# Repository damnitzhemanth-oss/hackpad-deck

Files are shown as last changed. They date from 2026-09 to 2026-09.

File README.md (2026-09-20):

# MacroPad
A 9-key *multi-functional* macropad with rotary encoder, OLED, and addressable RGB LEDs

*Note : This ReadMe is written by a human known as Hemanth from India, I am new to this and learning every day. Please highlight the mistakes I may have made.*

## Overview

This is my first **Stardance HackClub** project. I have officially worked on this project for 22+ hours. I want to thank all the people to who are responsible in creation of these organizations. 

## Functions 

- Modes like Dev, Editor, etc with different presets of keys.
- Contains a satisfying Mini Game.
(*Discussed in **depth** in upcoming sections*)

Assembly Render

## PCB  Design

I was already well versed with simple hardware projects using **Arduino UNO** and **ESP 8266**, but even though I knew about PCBs I never used them as they are expensive. Learning *KiCad* was pretty straight forward and easy.

Mainly routing was a bit challenging but everything else was easy. DRC have 0 errors except silkscreen warnings. 

## PCB Gallery

1. SCHEMATIC SVG 

Schematic Picture

2. Screenshots

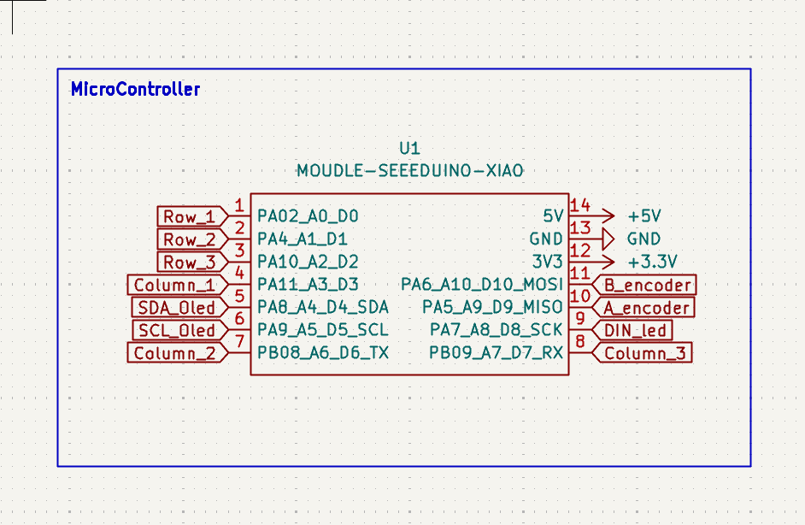
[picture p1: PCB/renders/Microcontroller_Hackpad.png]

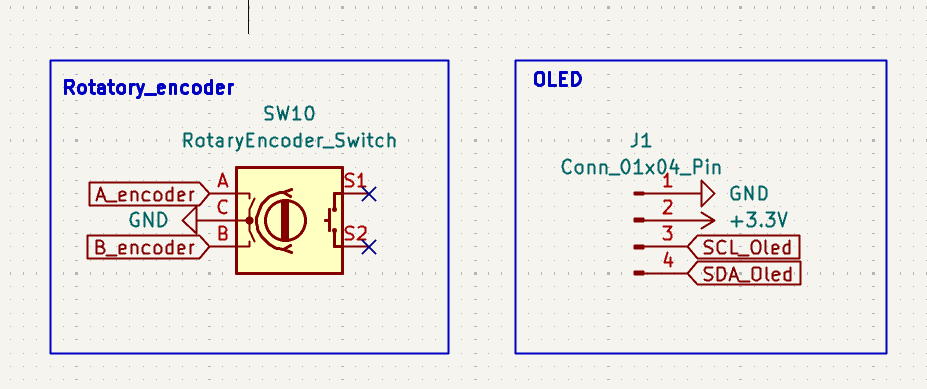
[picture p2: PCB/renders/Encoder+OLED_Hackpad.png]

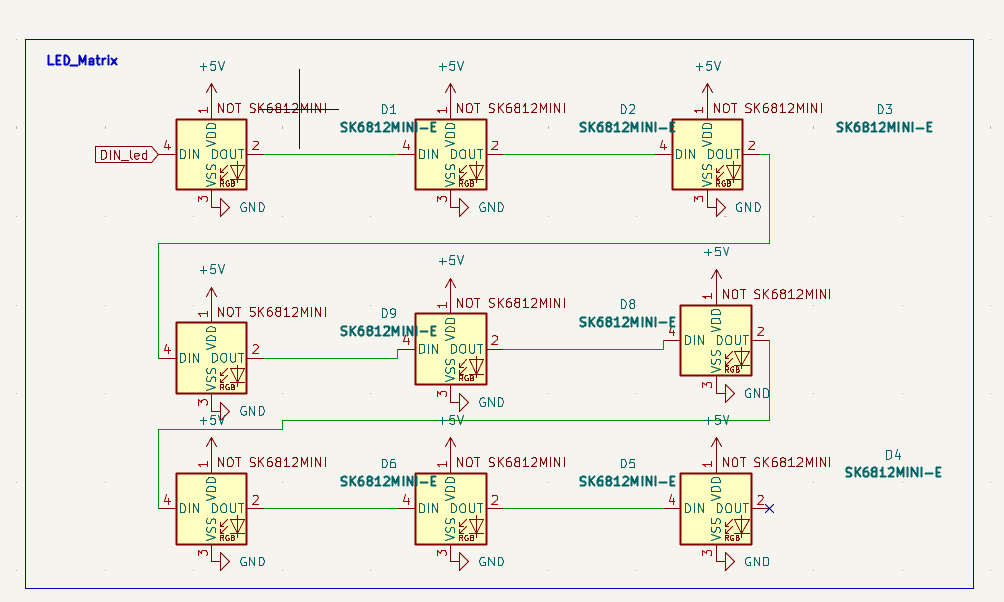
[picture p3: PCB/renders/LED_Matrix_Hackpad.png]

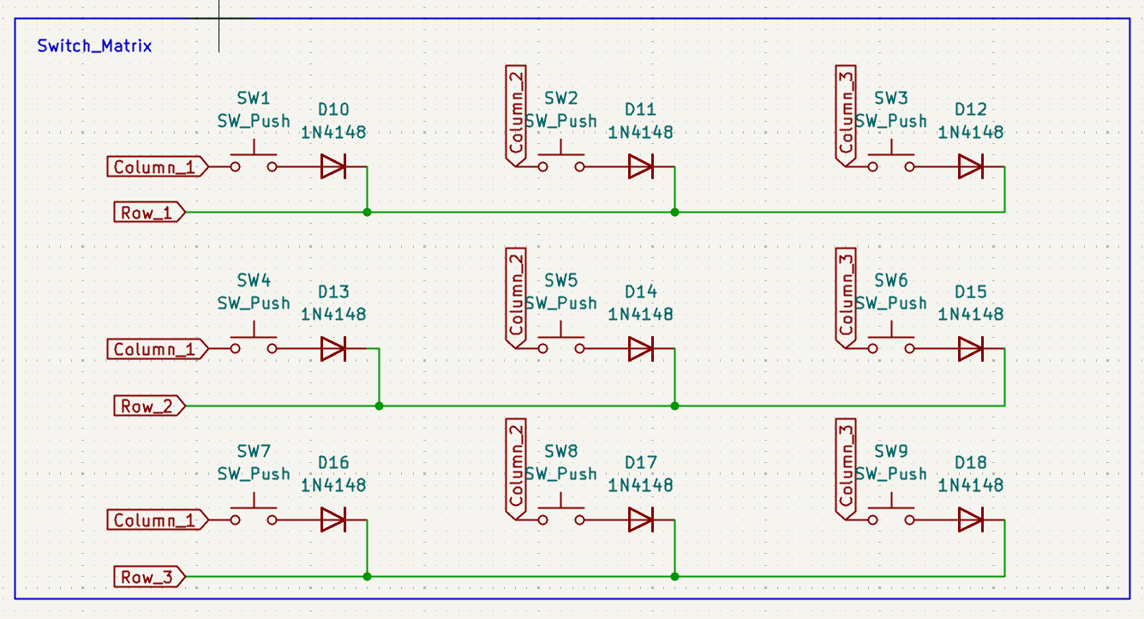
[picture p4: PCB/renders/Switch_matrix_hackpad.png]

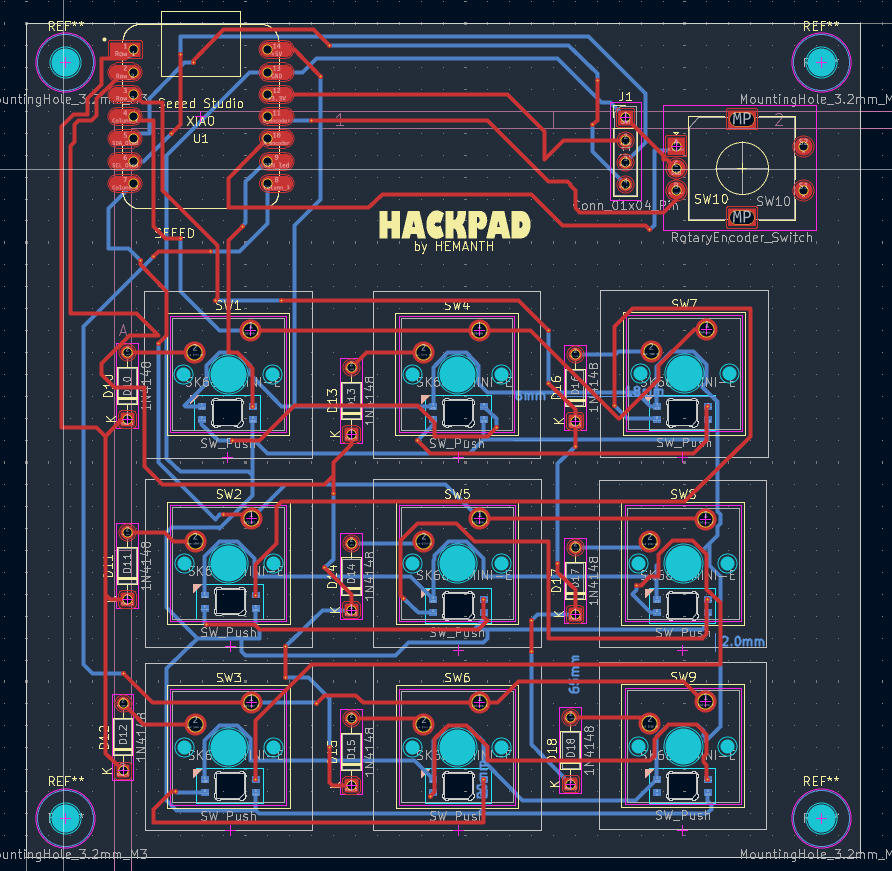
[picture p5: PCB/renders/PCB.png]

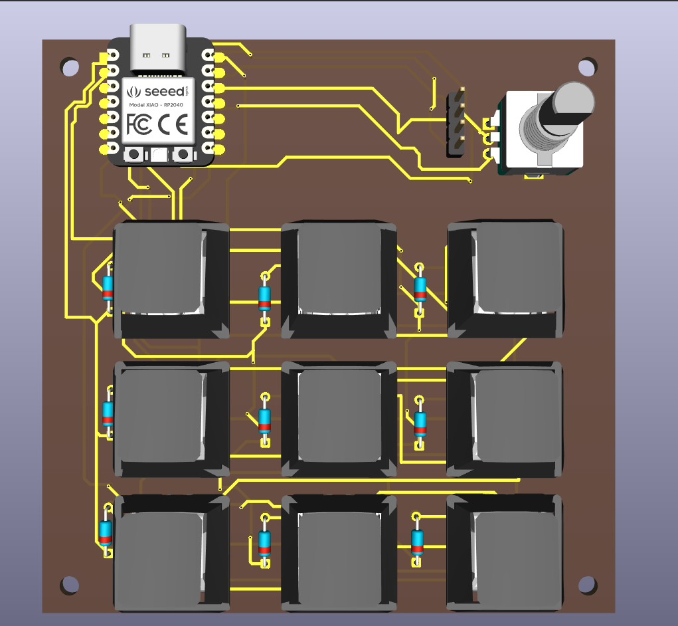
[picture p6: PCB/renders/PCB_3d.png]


## CAD Design

Cad was one of the field I had zero ball knowledge about. So designing it was fun but also was a pain. Due to daily internet cap I was not able to download Fusion 360, so OnShape was the way to go.
The design mainly consists of Base plate with Heatset Inserts and Top Plate with holes for M3 screws. PCB gets sandwiched between. All this was done in keeping +0.2 mm tolerance in mind.

## Cad Gallery.

Assembly Render
Assembly Render
Assembly Render
Plates
Plates
Plates
Plates

##  Functions

| Feature | Description |
|---|---|
|  **6 Modes** | Dev, Media, Video, Macro, Aesthetic, Games |
|  **Whack-a-LED Game** | Press the lit switch before time runs out |
| **DJ Mode** | Rainbow RGB animation across all 9 LEDs |
|  **Snowfall OLED** | Idle screen shows falling snowflakes |
|  **Rotary Encoder** | Volume control on every mode |
| **Per-Key RGB** | 9 addressable SK6812MINI-E LEDs |
|  **Live OLED Feedback** | Shows mode, key presses, and game score |

---

##  Modes

Cycle modes by **long-pressing SW7** (bottom-left key).

### 1. DEV — Editor & Typing
| Key | Action |
|-----|---|
| SW1–SW9 | Number keys 2–9 (numpad layout) |
| SW7 (tap) | ESC |
| SW7 (hold) | Next mode |

### 2. MEDIA — Playback Controls
| Key | Action |
|-----|---|
| SW1 | Play / Pause |
| SW2 | Stop |
| SW3 | Mute |
| SW4 | Previous Track |
| SW6 | Next Track |
| SW8 | Volume Down |
| SW9 | Volume Up |

### 3. VIDEO — DaVinci Resolve Editing
| Key | Action |
|-----|---|
| SW1 | Split Clip |
| SW2 | Undo |
| SW3 | Redo |
| SW4 | Mark In |
| SW5 | Mark Out |
| SW6 | Paste Attributes |
| SW8 | Play / Pause |
| SW9 | Backspace |

### 4. MACRO — Launcher & Productivity
| Key | Action |
|-----|---|
| SW1–SW3 | Open App 1 / 2 / 3 |
| SW4–SW6 | Copy / Paste / Cut |
| SW8–SW9 | Select All / Save |

### 5. AESTHETIC — DJ Mode 
RGB LEDs dance through a rotating rainbow. No key output — pure visual vibes.

### 6. GAMES — Whack-a-LED 
A random LED lights up **green**. Press its switch within **3 seconds** to score. Wrong key or timeout resets your score to 0 and flashes all LEDs red.

---

## Bill of Materials

| # | Component | Qty | Source |
|---|---|-----|---|
| 1 | Seeed XIAO RP2040 | 1 | Hack Club Kit |
| 2 | Gateron KS-3 MX Switches | 9 | Hack Club Kit |
| 3 | 1N4148 Through-hole Diodes | 9 | Hack Club Kit |
| 4 | Alps EC11E Rotary Encoder | 1 | Hack Club Kit |
| 5 | SK6812MINI-E RGB LEDs | 9 | Hack Club Kit |
| 6 | 0.91" SSD1306 OLED Display (128×32) | 1 | Hack Club Kit |
| 7 | White DSA Keycaps | 9 | Hack Club Kit |
| 8 | M3×16mm Screws *(trim to 13mm)* | 4 | Hack Club Kit |
| 9 | M3×5mm×4mm Heatset Inserts | 4 | Hack Club Kit |
| 10 | 3D Printed Case (Base + Top Plate) | 1 set | 

---

## Firmware

Written in **Python** using **KMK** on **CircuitPython**.

See [`Firmware/main.py`](Firmware/main.py) for the full source.

---

## AI USAGE

I used AI/ Online resources to learn but never automate anything. You can checkout Lapse recording from lookout too.

## Credits

- **[Hack Club](https://hackclub.com/)** — for the kit and the program
- **Star Dance** — for organizing this buildathon
- **[KMK Firmware](https://github.com/KMKfw/kmk_firmware)** — Python keyboard firmware
- **Hack Club Hackpad team** — for the guides and KiCad care package
- Special shoutout to Logan Peterson, whose design inspired me a lot.

---

##  License

Open source, but you are responsible if it creates a black hole in your house.

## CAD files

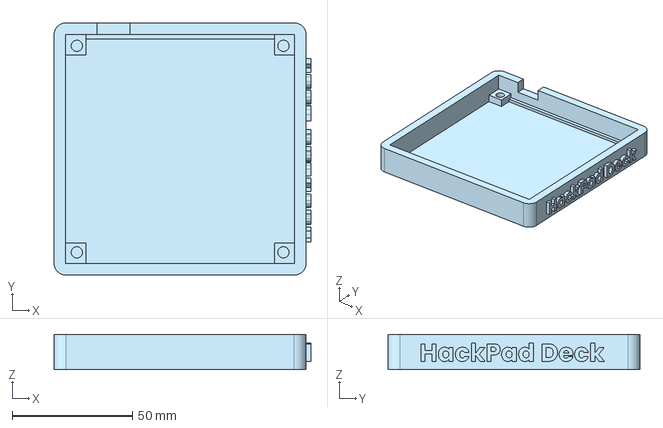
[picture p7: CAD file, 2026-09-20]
production/Base_Plate.step
107.0 x 105.0 x 14.6 mm

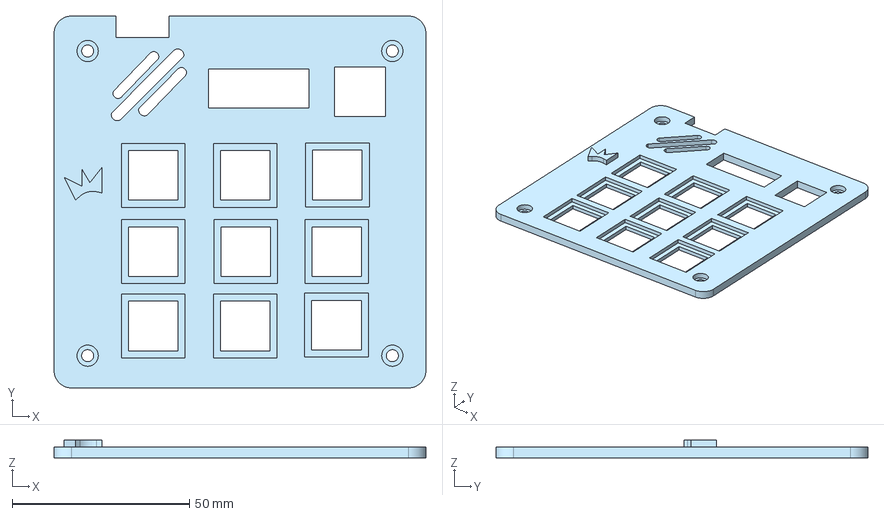
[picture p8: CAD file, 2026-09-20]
production/Top_plate.step
105.0 x 105.0 x 5.00 mm

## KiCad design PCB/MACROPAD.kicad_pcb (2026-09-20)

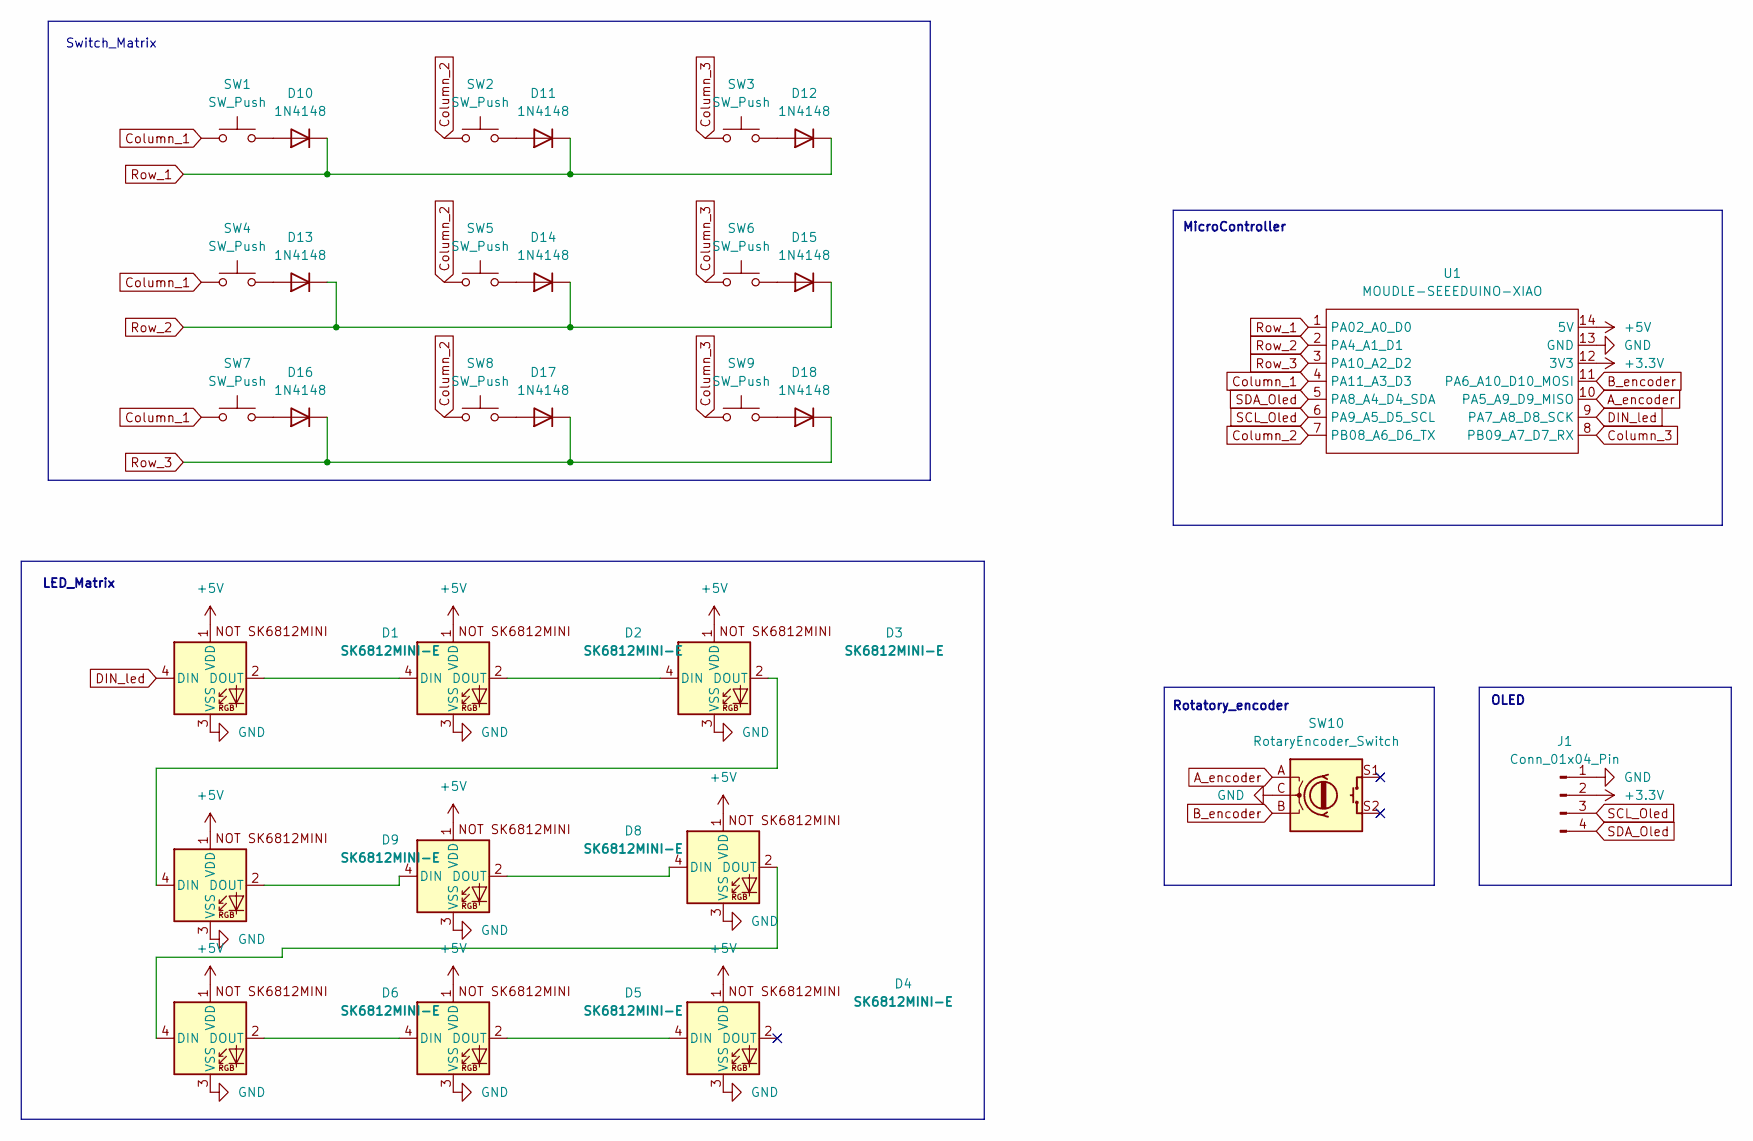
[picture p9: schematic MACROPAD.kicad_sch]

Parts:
D1, D2, D3, D4, D5, D6, D7, D8, D9: SK6812MINI-E; MX_SK6812MINI-E_fixed_mount_with3D
D10, D11, D12, D13, D14, D15, D16, D17, D18: 1N4148; D_DO-35_SOD27_P7.62mm_Horizontal
J1: Conn_01x04_Pin; Adafruit_SSD1306
SW1, SW2, SW3, SW4, SW5, SW6, SW7, SW8, SW9: SW_Push; SW_Cherry_MX_1.00u_PCB_3d
SW10: RotaryEncoder_Switch; RotaryEncoder_Alps_EC11E-Switch_Vertical_H20mm
U1: MOUDLE-SEEEDUINO-XIAO; XIAO-Generic-Hybrid-14P-2.54-21X17.8MM

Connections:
+3.3V: J1.2, U1.12 (3V3)
+5V: D1.1 (VDD), D2.1 (VDD), D3.1 (VDD), D4.1 (VDD), D5.1 (VDD), D6.1 (VDD), D7.1 (VDD), D8.1 (VDD), D9.1 (VDD), U1.14 (5V)
A_encoder: SW10.A, U1.10 (PA5_A9_D9_MISO)
B_encoder: SW10.B, U1.11 (PA6_A10_D10_MOSI)
Column_1: SW1.1, SW4.1, SW7.1, U1.4 (PA11_A3_D3)
Column_2: SW2.1, SW5.1, SW8.1, U1.7 (PB08_A6_D6_TX)
Column_3: SW3.1, SW6.1, SW9.1, U1.8 (PB09_A7_D7_RX)
DIN_led: D1.4 (DIN), U1.9 (PA7_A8_D8_SCK)
GND: D1.3 (VSS), D2.3 (VSS), D3.3 (VSS), D4.3 (VSS), D5.3 (VSS), D6.3 (VSS), D7.3 (VSS), D8.3 (VSS), D9.3 (VSS), J1.1, SW10.C, U1.13 (GND)
unnamed: D1.2 (DOUT), D2.4 (DIN)
unnamed: D2.2 (DOUT), D3.4 (DIN)
unnamed: D3.2 (DOUT), D9.4 (DIN)
unnamed: D4.4 (DIN), D5.2 (DOUT)
unnamed: D5.4 (DIN), D6.2 (DOUT)
unnamed: D6.4 (DIN), D7.2 (DOUT)
unnamed: D7.4 (DIN), D8.2 (DOUT)
unnamed: D8.4 (DIN), D9.2 (DOUT)
unnamed: D10.2 (A), SW1.2
unnamed: D11.2 (A), SW2.2
unnamed: D12.2 (A), SW3.2
unnamed: D13.2 (A), SW4.2
unnamed: D14.2 (A), SW5.2
unnamed: D15.2 (A), SW6.2
unnamed: D16.2 (A), SW7.2
unnamed: D17.2 (A), SW8.2
unnamed: D18.2 (A), SW9.2
Row_1: D10.1 (K), D11.1 (K), D12.1 (K), U1.1 (PA02_A0_D0)
Row_2: D13.1 (K), D14.1 (K), D15.1 (K), U1.2 (PA4_A1_D1)
Row_3: D16.1 (K), D17.1 (K), D18.1 (K), U1.3 (PA10_A2_D2)
SCL_Oled: J1.3, U1.6 (PA9_A5_D5_SCL)
SDA_Oled: J1.4, U1.5 (PA8_A4_D4_SDA)

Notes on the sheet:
LED_Matrix
MicroController
Rotatory_encoder
Switch_Matrix
OLED

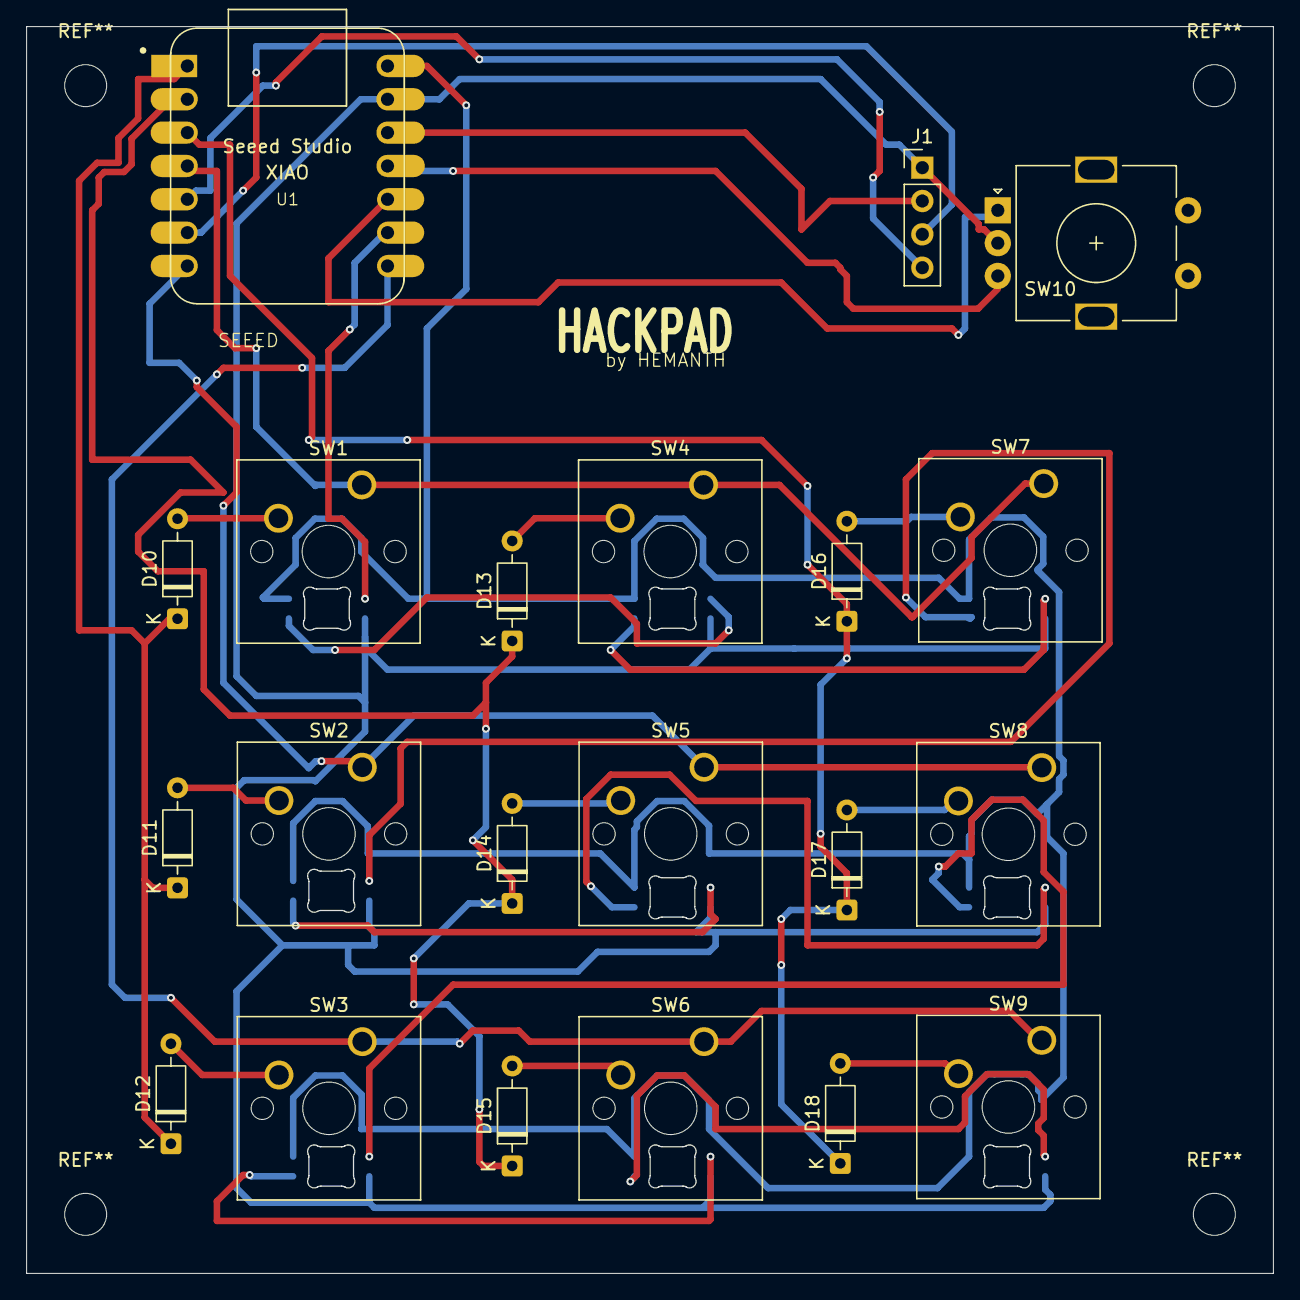
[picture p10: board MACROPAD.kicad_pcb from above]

Board: 2 copper layers, 95.0 x 95.0 mm, 30 parts (0 on the bottom side), 31 nets.

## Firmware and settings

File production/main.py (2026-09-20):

import board
import time
import random
import busio
import displayio
import terminalio
from adafruit_display_text import label
import adafruit_displayio_ssd1306

from kmk.kmk_keyboard import KMKKeyboard
from kmk.keys import KC, Key
from kmk.scanners import DiodeOrientation
from kmk.modules.layers import Layers
from kmk.modules.encoder import EncoderHandler
from kmk.modules.holdtap import HoldTap
from kmk.extensions.RGB import RGB, AnimationModes
from kmk.modules import Module

keyboard = KMKKeyboard()

keyboard.row_pins = (board.D0, board.D1, board.D2)
keyboard.col_pins = (board.D3, board.D6, board.D7)
keyboard.diode_orientation = DiodeOrientation.COL2ROW

MODE_NAMES = ["DEV", "MEDIA", "VIDEO", "MACRO", "AESTHETIC", "GAMES"]
current_mode = 0

MODE_COLORS = {
    0: {"idle": (0, 0, 40),    "accent": (255, 255, 255)},
    1: {"idle": (40, 0, 40),   "accent": (0, 255, 60)},
    2: {"idle": (50, 20, 0),   "accent": (0, 200, 255)},
    3: {"idle": (40, 0, 0),    "accent": (255, 220, 0)},
    4: {"idle": (0, 0, 0),     "accent": (0, 0, 0)},
    5: {"idle": (0, 0, 0),     "accent": (0, 0, 0)},
}

keyboard.active_layers = [current_mode]

layers_ext = Layers()
keyboard.modules.append(layers_ext)


class ModeCycleKey(Key):
    def on_press(self, keyboard):
        global current_mode
        current_mode = (current_mode + 1) % len(MODE_NAMES)
        keyboard.active_layers = [current_mode]
        status.on_mode_changed()


MODE_CYCLE = ModeCycleKey()

hold_tap = HoldTap(tap_time=200)
keyboard.modules.append(hold_tap)

SW7_HOLDTAP = KC.HT(KC.ESC, MODE_CYCLE)

keyboard.keymap = [
    [
        KC.N7, KC.N8, KC.N9,
        KC.N4, KC.N5, KC.N6,
        SW7_HOLDTAP, KC.N2, KC.N3,
    ],
    [
        KC.MPLY, KC.MSTP, KC.MUTE,
        KC.MPRV, KC.NO,   KC.MNXT,
        SW7_HOLDTAP, KC.VOLD, KC.VOLU,
    ],
    [
        KC.LCTL(KC.LSFT(KC.N3)),
        KC.LCTL(KC.Z),
        KC.LCTL(KC.LSFT(KC.Z)),
        KC.I,
        KC.O,
        KC.LCTL(KC.LSFT(KC.V)),
        SW7_HOLDTAP, KC.SPC, KC.BSPC,
    ],
    [
        KC.LGUI(KC.N1), KC.LGUI(KC.N2), KC.LGUI(KC.N3),
        KC.LCTL(KC.C),  KC.LCTL(KC.V),  KC.LCTL(KC.X),
        SW7_HOLDTAP,    KC.LCTL(KC.A),  KC.LCTL(KC.S),
    ],
    [
        KC.NO, KC.NO, KC.NO,
        KC.NO, KC.NO, KC.NO,
        SW7_HOLDTAP, KC.NO, KC.NO,
    ],
    [
        KC.NO, KC.NO, KC.NO,
        KC.NO, KC.NO, KC.NO,
        SW7_HOLDTAP, KC.NO, KC.NO,
    ],
]

encoder_handler = EncoderHandler()
keyboard.modules.append(encoder_handler)

encoder_handler.pins = ((board.D9, board.D10, None),)
encoder_handler.map = [((KC.VOLD, KC.VOLU),)]

rgb_ext = RGB(
    pixel_pin=board.D8,
    num_pixels=9,
    animation_mode=AnimationModes.STATIC,
    val_limit=100,
)
keyboard.extensions.append(rgb_ext)

LED_CHAIN_ORDER = [1, 2, 3, 9, 8, 7, 6, 5, 4]
SW_TO_LED_INDEX = {sw: idx for idx, sw in enumerate(LED_CHAIN_ORDER)}
LED_INDEX_TO_SW = {idx: sw for sw, idx in SW_TO_LED_INDEX.items()}

COORD_TO_SW = {
    (0, 0): 1, (0, 1): 2, (0, 2): 3,
    (1, 0): 4, (1, 1): 5, (1, 2): 6,
    (2, 0): 7, (2, 1): 8, (2, 2): 9,
}


def hsv_to_rgb(h, s, v):
    c = v * s
    x = c * (1 - abs((h / 60.0) % 2 - 1))
    m = v - c
    if   h < 60:  r, g, b = c, x, 0
    elif h < 120: r, g, b = x, c, 0
    elif h < 180: r, g, b = 0, c, x
    elif h < 240: r, g, b = 0, x, c
    elif h < 300: r, g, b = x, 0, c
    else:         r, g, b = c, 0, x
    return (int((r + m) * 255), int((g + m) * 255), int((b + m) * 255))


displayio.release_displays()
i2c = busio.I2C(board.D5, board.D4)
display_bus = displayio.I2CDisplay(i2c, device_address=0x3C)
display = adafruit_displayio_ssd1306.SSD1306(display_bus, width=128, height=32)

text_group = displayio.Group()
mode_label = label.Label(terminalio.FONT, text="DEV", x=4, y=8, scale=2)
key_label  = label.Label(terminalio.FONT, text="", x=4, y=24, scale=1)
text_group.append(mode_label)
text_group.append(key_label)

snow_bitmap = displayio.Bitmap(128, 32, 2)
snow_palette = displayio.Palette(2)
snow_palette[0] = 0x000000
snow_palette[1] = 0xFFFFFF
snow_tile = displayio.TileGrid(snow_bitmap, pixel_shader=snow_palette)
snow_group = displayio.Group()
snow_group.append(snow_tile)

display.root_group = text_group

MAX_SNOW = 35
snow_x = [random.randint(0, 127) for _ in range(MAX_SNOW)]
snow_y = [random.randint(0, 31)  for _ in range(MAX_SNOW)]


def draw_snowfall():
    snow_bitmap.fill(0)
    for i in range(MAX_SNOW):
        if 0 <= snow_x[i] < 128 and 0 <= snow_y[i] < 32:
            snow_bitmap[snow_x[i], snow_y[i]] = 1
        snow_y[i] += 1
        if random.random() > 0.5:
            snow_x[i] += random.randint(-1, 1)
            snow_x[i] = max(0, min(127, snow_x[i]))
        if snow_y[i] >= 32:
            snow_y[i] = 0
            snow_x[i] = random.randint(0, 127)


def show_text_mode(mode_name, key_text=""):
    mode_label.text = mode_name
    key_label.text = key_text
    display.root_group = text_group


def show_snow_mode():
    display.root_group = snow_group


GAME_TIMEOUT = 3.0

game_target    = 1
game_score     = 0
game_lit_at    = 0.0
game_reset_until = 0.0


def game_start_round():
    global game_target, game_lit_at, game_reset_until
    game_target = random.randint(1, 9)
    game_lit_at = time.monotonic()
    game_reset_until = 0
    for i in range(9):
        rgb_ext.pixels[i] = (0, 0, 0)
    rgb_ext.pixels[SW_TO_LED_INDEX[game_target]] = (0, 255, 100)


def game_reset_score():
    global game_score, game_reset_until
    game_score = 0
    game_reset_until = time.monotonic() + 0.5
    for i in range(9):
        rgb_ext.pixels[i] = (255, 0, 0)


IDLE_TIMEOUT   = 3.0
FRAME_INTERVAL = 0.05
FLASH_DURATION = 0.15


class HackPadStatus(Module):

    def __init__(self):
        self.last_activity   = time.monotonic()
        self.last_frame      = 0.0
        self.snowfall_active = False
        self.flash_queue     = []

    def during_bootup(self, keyboard):
        self.apply_idle_rgb()
        show_text_mode(MODE_NAMES[current_mode], "Ready")
        return keyboard

    def before_matrix_scan(self, keyboard):
        now = time.monotonic()
        mode_name = MODE_NAMES[current_mode]

        if self.flash_queue and now >= self.flash_queue[0][1]:
            for pixel_idx, expire in list(self.flash_queue):
                if now >= expire:
                    self.flash_queue.remove((pixel_idx, expire))
                    if mode_name not in ("AESTHETIC", "GAMES"):
                        rgb_ext.pixels[pixel_idx] = MODE_COLORS[current_mode]["idle"]

        if now - self.last_frame >= FRAME_INTERVAL:
            self.last_frame = now

            if mode_name == "AESTHETIC":
                self._animate_aesthetic(now)
            elif mode_name == "GAMES":
                self._animate_games(now)
            elif self.snowfall_active:
                draw_snowfall()

        if mode_name not in ("GAMES",):
            idle_time = now - self.last_activity
            if idle_time > IDLE_TIMEOUT and not self.snowfall_active:
                self.snowfall_active = True
                show_snow_mode()
            elif idle_time <= IDLE_TIMEOUT and self.snowfall_active:
                self.snowfall_active = False
                show_text_mode(MODE_NAMES[current_mode], "Ready")

        return keyboard

    def after_matrix_scan(self, keyboard):
        return keyboard

    def process_key(self, keyboard, key, is_pressed, int_coord):
        if int_coord is None:
            return key

        row = int_coord // len(keyboard.col_pins)
        col = int_coord % len(keyboard.col_pins)
        sw = COORD_TO_SW.get((row, col))
        if sw is None:
            return key

        mode_name = MODE_NAMES[current_mode]

        if mode_name == "GAMES":
            if is_pressed:
                self._handle_game_press(sw)
            return None

        if is_pressed:
            self.last_activity = time.monotonic()
            self.snowfall_active = False
            self._flash_key(sw)
            self._show_text(sw)

        return key

    def before_hid_send(self, keyboard):
        return keyboard

    def after_hid_send(self, keyboard):
        return keyboard

    def on_powersave_enable(self, keyboard):
        return keyboard

    def on_powersave_disable(self, keyboard):
        return keyboard

    def on_mode_changed(self):
        global game_score
        self.last_activity = time.monotonic()
        self.snowfall_active = False

        mode_name = MODE_NAMES[current_mode]

        if mode_name == "GAMES":
            game_score = 0
            game_start_round()
            show_text_mode("GAMES", "Score: 0")
        elif mode_name == "AESTHETIC":
            for i in range(9):
                rgb_ext.pixels[i] = (0, 0, 0)
            show_text_mode("AESTHETIC", "DJ mode")
        else:
            self.apply_idle_rgb()
            show_text_mode(mode_name, "Ready")

    def apply_idle_rgb(self):
        mode_name = MODE_NAMES[current_mode]
        if mode_name in ("AESTHETIC", "GAMES"):
            return
        color = MODE_COLORS[current_mode]["idle"]
        for i in range(9):
            rgb_ext.pixels[i] = color

    def _flash_key(self, sw):
        if MODE_NAMES[current_mode] in ("AESTHETIC", "GAMES"):
            return
        pixel_idx = SW_TO_LED_INDEX.get(sw)
        if pixel_idx is None:
            return
        accent = MODE_COLORS[current_mode]["accent"]
        rgb_ext.pixels[pixel_idx] = accent
        self.flash_queue.append((pixel_idx, time.monotonic() + FLASH_DURATION))

    def _show_text(self, sw):
        show_text_mode(MODE_NAMES[current_mode], "SW{}".format(sw))

    def _animate_aesthetic(self, now):
        phase = (now * 300) % 360
        for i in range(9):
            hue = (phase + i * 40) % 360
            r, g, b = hsv_to_rgb(hue, 1.0, 0.7)
            rgb_ext.pixels[i] = (r, g, b)

    def _animate_games(self, now):
        if game_reset_until and now >= game_reset_until:
            game_start_round()
        elif now - game_lit_at > GAME_TIMEOUT and not game_reset_until:
            game_reset_score()

    def _handle_game_press(self, sw):
        global game_score, game_reset_until

        if game_reset_until:
            return

        if sw == game_target:
            game_score += 1
            show_text_mode("GAMES", "Score: {}".format(game_score))
            game_start_round()
        else:
            game_reset_score()
            show_text_mode("GAMES", "Miss! Reset")


status = HackPadStatus()
keyboard.modules.append(status)

if __name__ == "__main__":
    keyboard.go()
